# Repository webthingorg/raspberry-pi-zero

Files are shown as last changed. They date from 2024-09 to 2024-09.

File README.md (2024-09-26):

📸 Raspberry Pi Zero Hardware

## Pictures

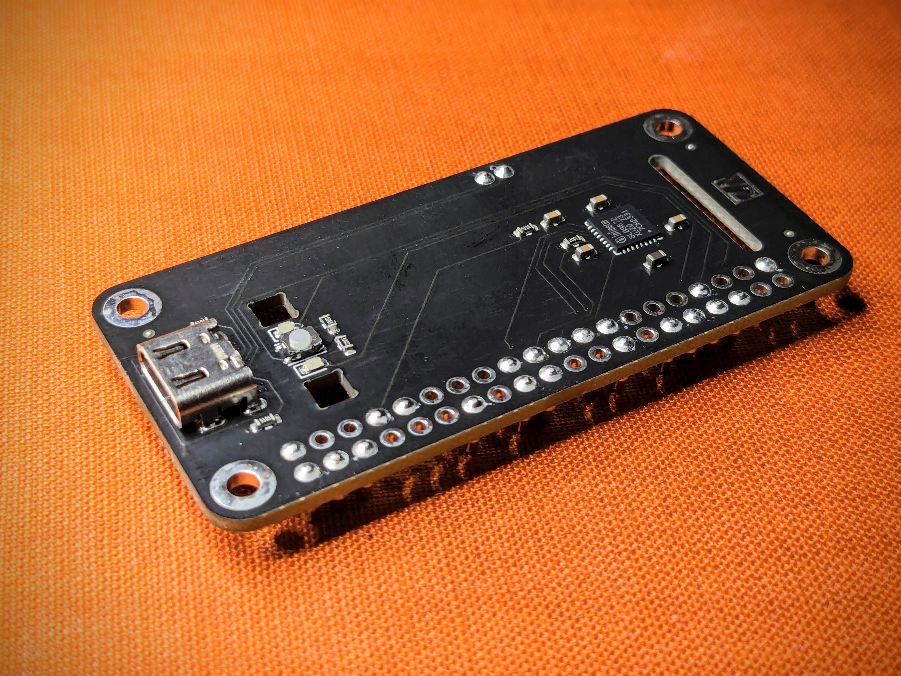
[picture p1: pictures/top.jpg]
top


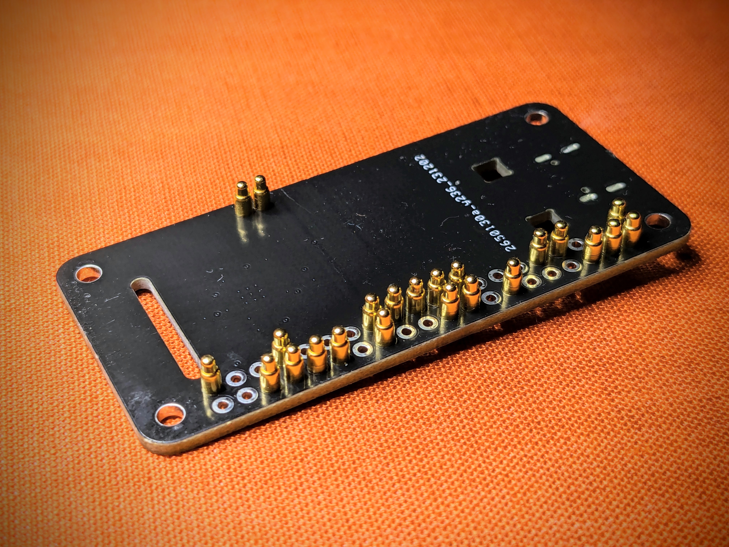
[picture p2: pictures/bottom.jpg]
bottom


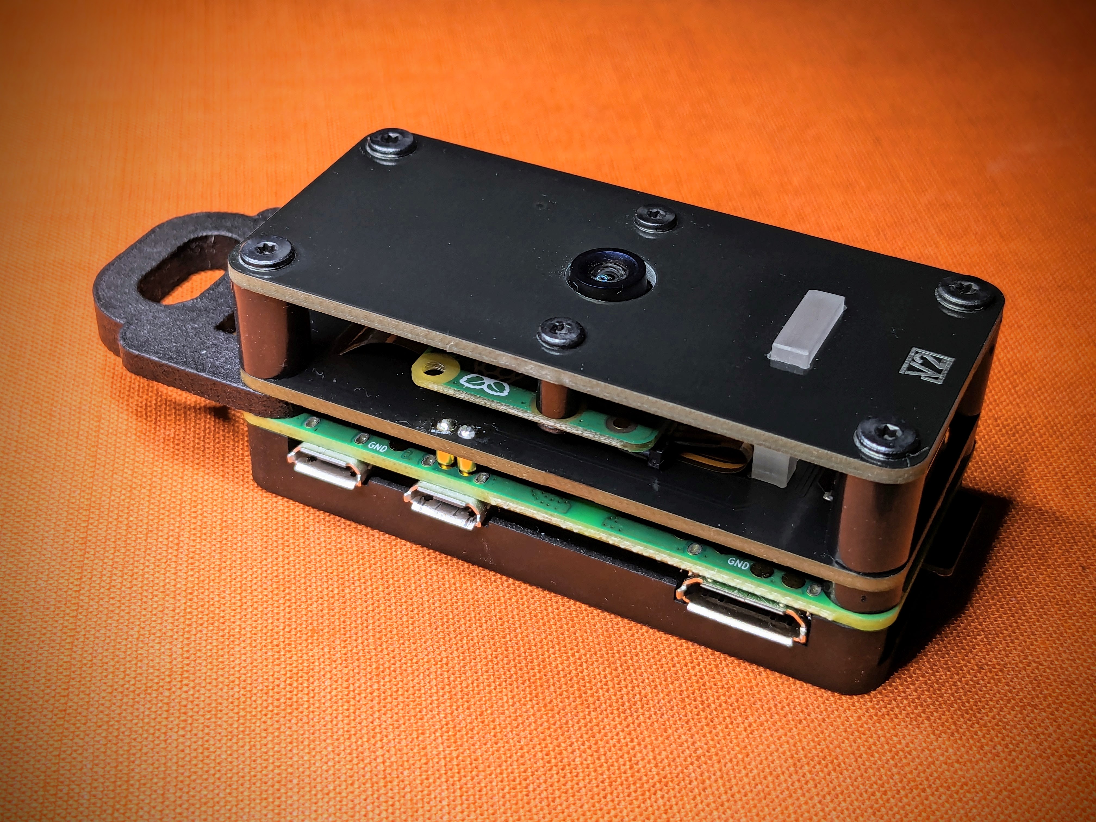
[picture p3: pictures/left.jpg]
left


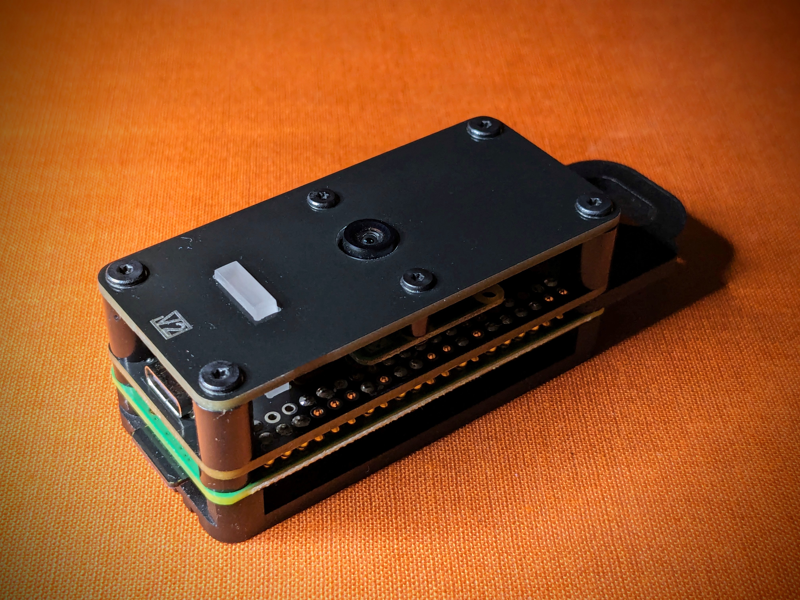
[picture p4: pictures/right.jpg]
rigth


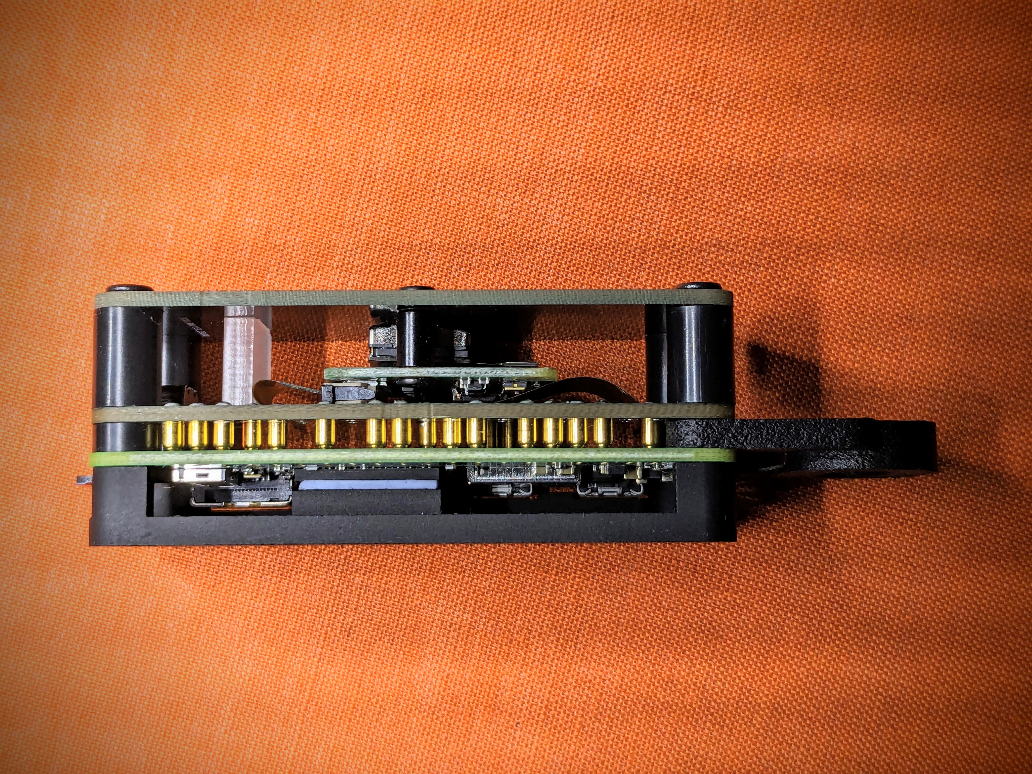
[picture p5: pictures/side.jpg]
side


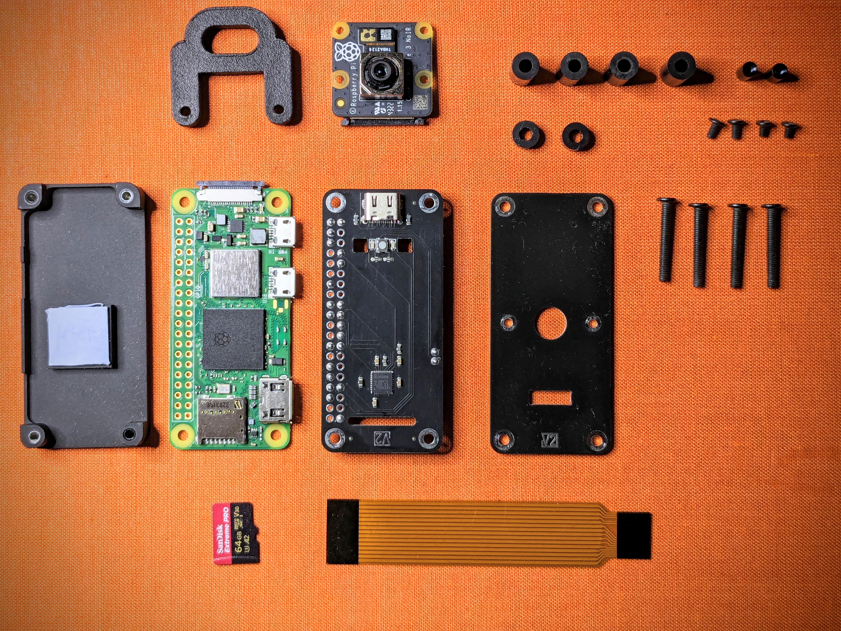
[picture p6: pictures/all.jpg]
all


## Schematic

[PDF](raspberry-pi-zero.pdf)

## Bill Of Materials

[Interactive BOM](https://gitlab.com/webthing.org/raspberry-pi-zero/-/raw/main/raspberry-pi-zero-bom.html?inline=false)

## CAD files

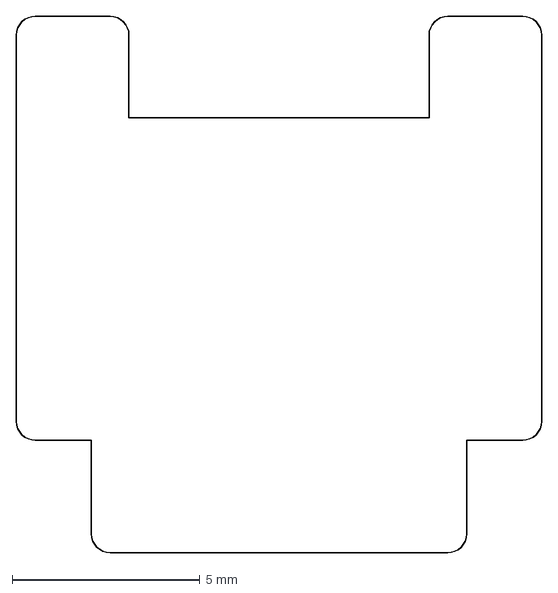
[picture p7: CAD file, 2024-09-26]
button-laser-10mm.dxf
14.0 x 14.3 mm

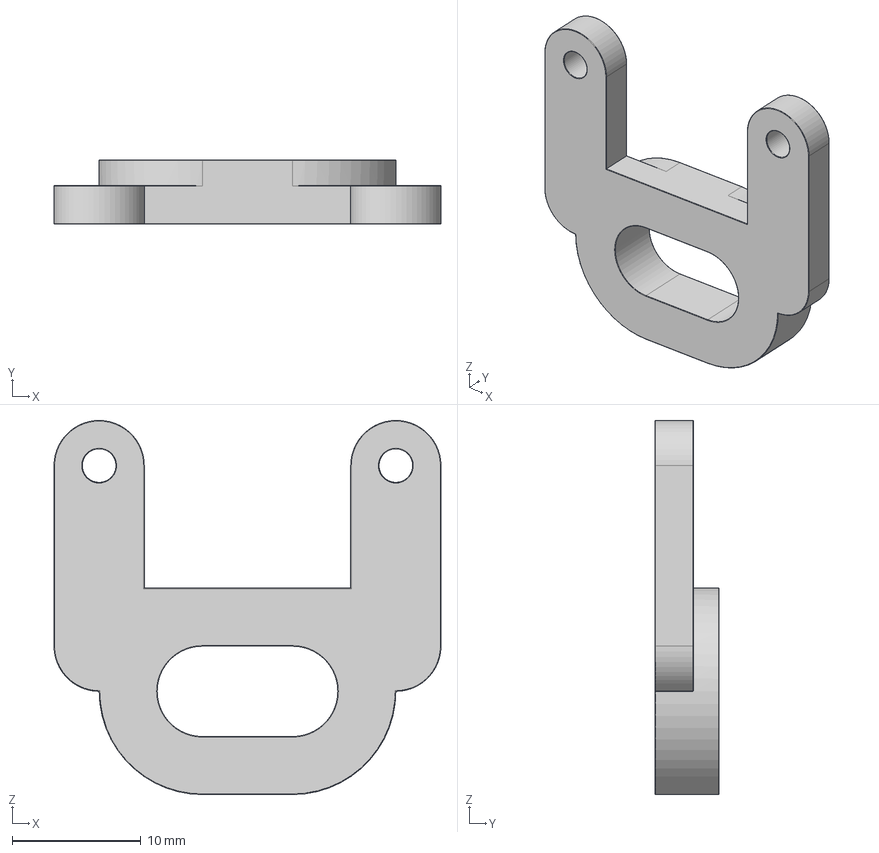
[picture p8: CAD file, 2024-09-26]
hanger.step
30.0 x 5.00 x 29.0 mm

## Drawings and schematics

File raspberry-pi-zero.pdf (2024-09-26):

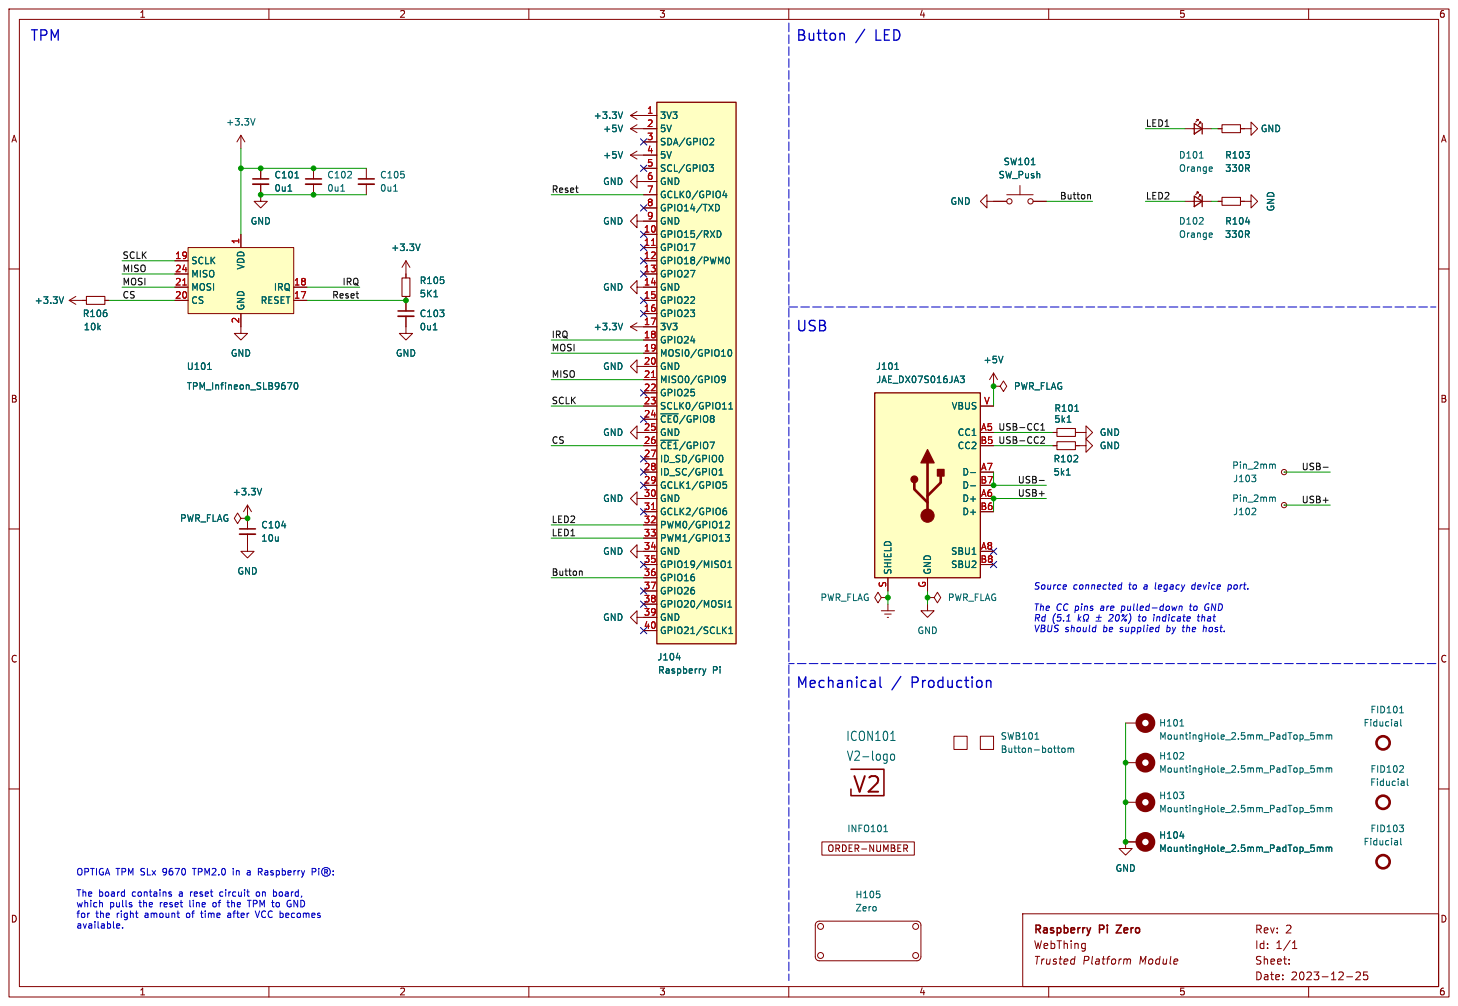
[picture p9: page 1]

SW101 SW_Push GND GND GND GND

for the right amount of time after VCC becomes available.

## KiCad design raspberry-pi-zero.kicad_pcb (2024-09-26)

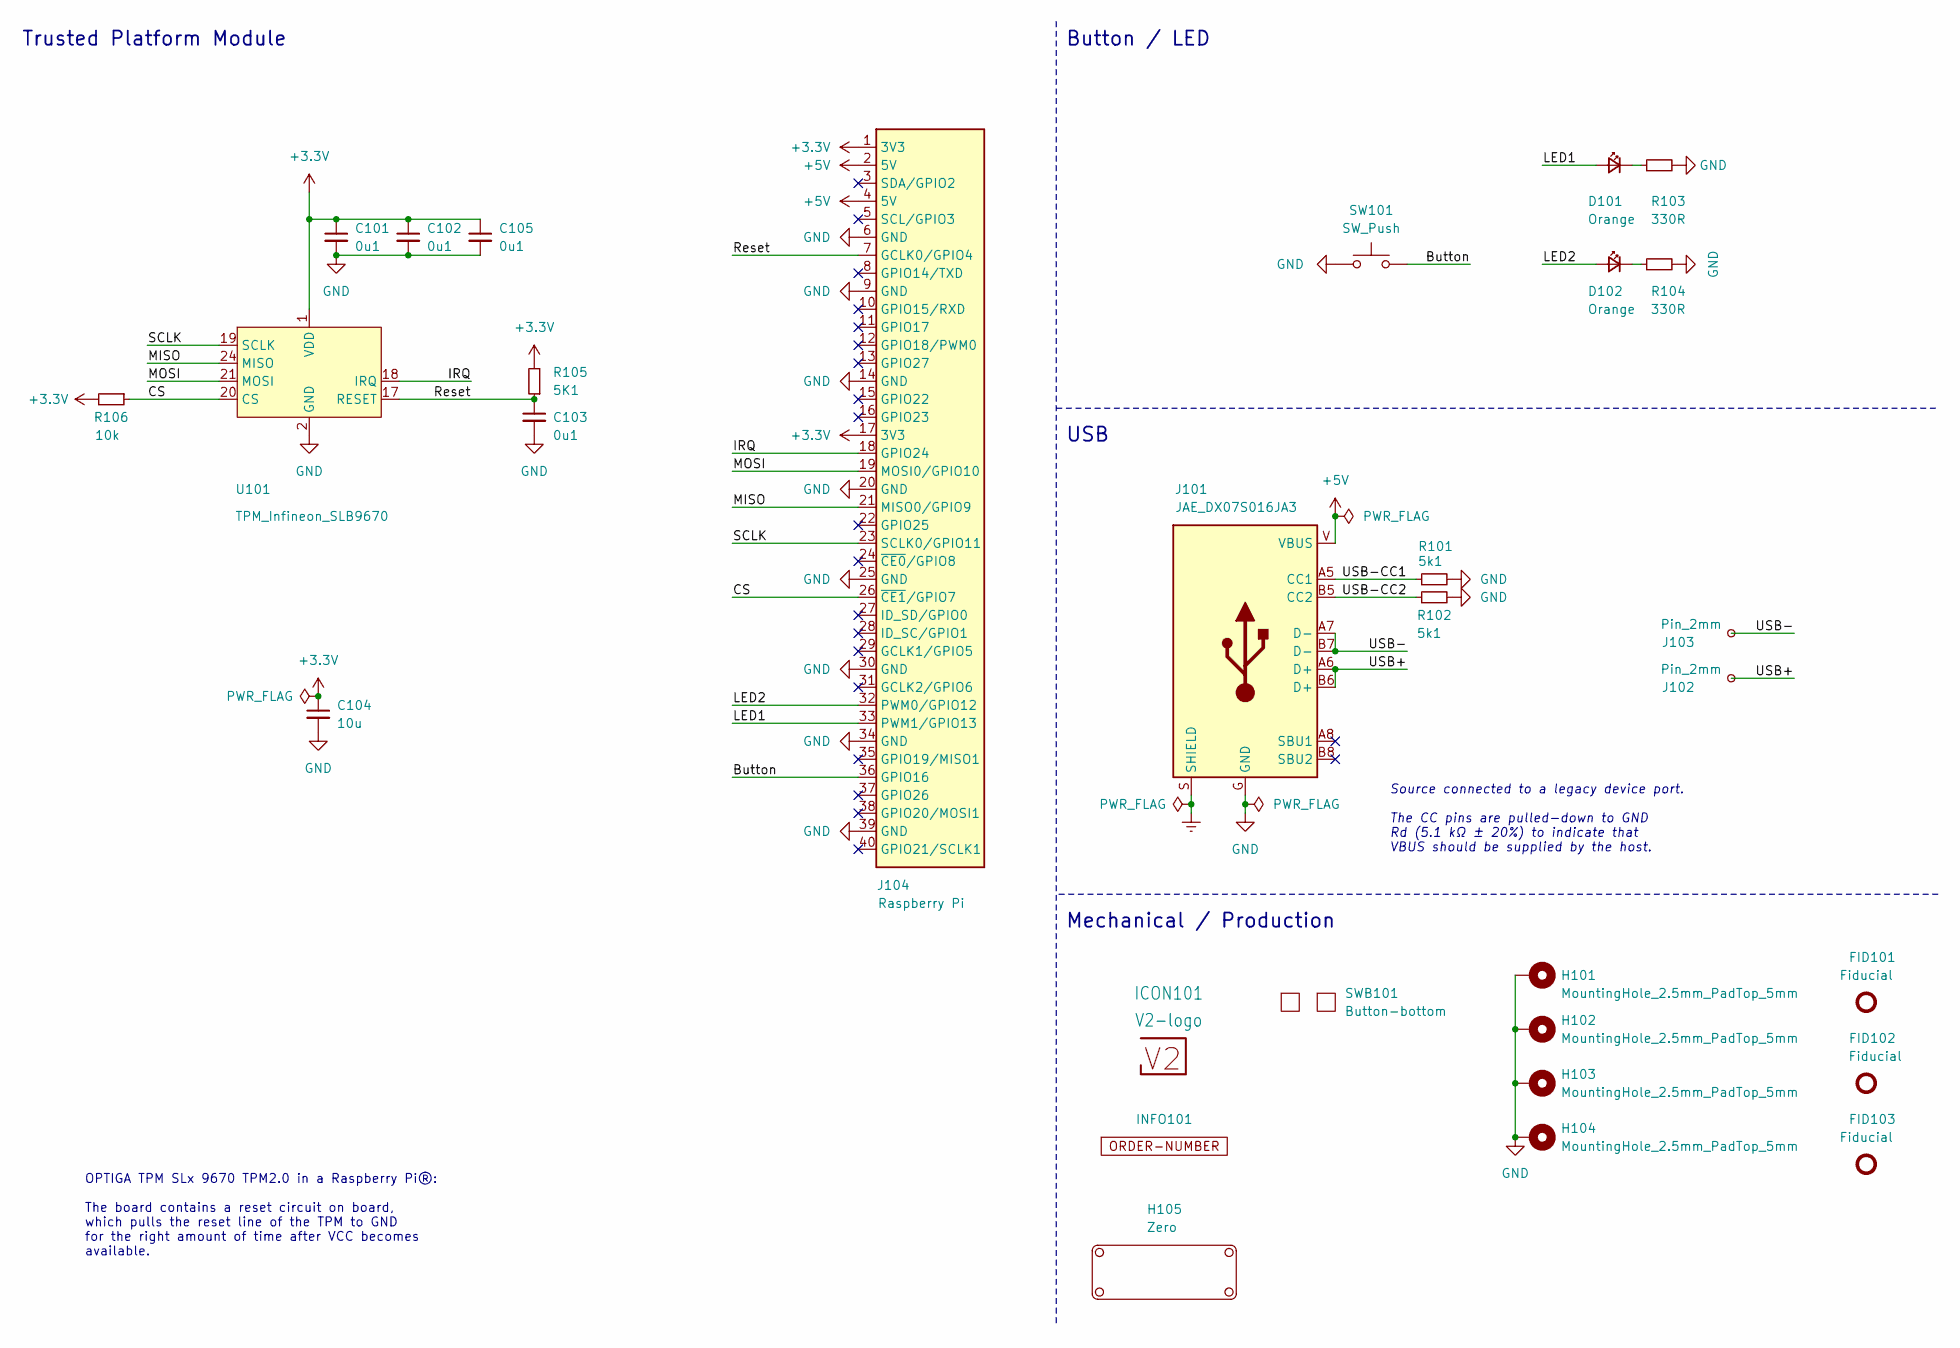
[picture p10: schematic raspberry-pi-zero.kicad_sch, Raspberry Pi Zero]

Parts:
C101, C102, C103, C105: 0u1; C_0603_1608Metric
C104: 10u; C_0603_1608Metric
D101, D102: Orange; LED_0603_1608Metric
FID101, FID102, FID103: Fiducial; Fiducial_0.5mm_Mask1mm_Paste
H101, H102, H103, H104: MountingHole_2.5mm_PadTop_5mm
H105: Zero
ICON101: V2-logo; Logo_Small
INFO101: ORDER-NUMBER; Order_Number
J101: JAE_DX07S016JA3
J102, J103: Pin_2mm
J104: Raspberry Pi; Connector_PogoPins
R101, R102: 5k1; R_0603_1608Metric
R103, R104: 330R; R_0603_1608Metric
R105: 5K1; R_0603_1608Metric
R106: 10k; R_0603_1608Metric
SW101: SW_Push; SKSG
SWB101: Button-bottom; PCB_Button-bottom
U101: TPM_Infineon_SLB9670; QFN-32-1EP_5x5mm_P0.5mm_EP3.6x3.6mm_ThermalVias

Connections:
+3.3V: C101.1, C102.1, C104.1, C105.1, J104.1 (3V3), J104.17 (3V3), R105.2, R106.2, U101.1 (VDD), U101.8 (VDD), U101.14 (VDD), U101.22 (VDD)
+5V: J101.V (VBUS), J104.2 (5V), J104.4 (5V)
/Button: J104.36 (GPIO16), SW101.2
/CS: J104.26 (~CE1/GPIO7), R106.1, U101.20 (CS)
/IRQ: J104.18 (GPIO24), U101.18 (IRQ)
/LED1: D101.2 (A), J104.33 (PWM1/GPIO13)
/LED2: D102.2 (A), J104.32 (PWM0/GPIO12)
/MISO: J104.21 (MISO0/GPIO9), U101.24 (MISO)
/MOSI: J104.19 (MOSI0/GPIO10), U101.21 (MOSI)
/Reset: C103.1, J104.7 (GCLK0/GPIO4), R105.1, U101.17 (RESET)
/SCLK: J104.23 (SCLK0/GPIO11), U101.19 (SCLK)
/USB+: J101.A6 (D+), J101.B6 (D+), J102.1
/USB-: J101.A7 (D-), J101.B7 (D-), J103.1
/USB-CC1: J101.A5 (CC1), R101.1
/USB-CC2: J101.B5 (CC2), R102.1
Earth: J101.S (SHIELD)
GND: C101.2, C102.2, C103.2, C104.2, C105.2, H101.1, H102.1, H103.1, H104.1, J101.G (GND), J104.6 (GND), J104.9 (GND), J104.14 (GND), J104.20 (GND), J104.25 (GND), J104.30 (GND), J104.34 (GND), J104.39 (GND), R101.2, R102.2, R103.2, R104.2, SW101.1, U101.2 (GND), U101.9 (GND), U101.16 (GND), U101.23 (GND), U101.32 (GND), U101.33 (GND)
unnamed: D101.1 (K), R103.1
unnamed: D102.1 (K), R104.1

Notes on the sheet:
Button / LED
Trusted Platform Module
 Source connected to a legacy device port. The CC pins are pulled-down to GND Rd (5.1 kΩ ± 20%) to indicate that VBUS should be supplied by the host.
Mechanical / Production
OPTIGA TPM SLx 9670 TPM2.0 in a Raspberry Pi®: The board contains a reset circuit on board, which pulls the reset line of the TPM to GND for the right amount of time after VCC becomes available.
USB

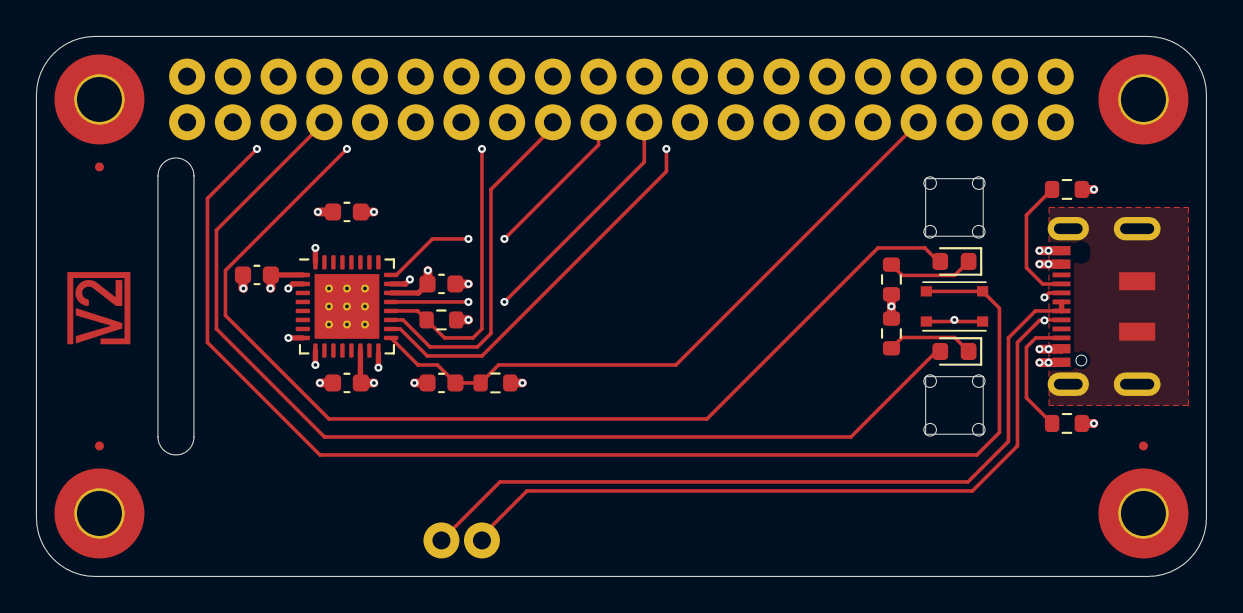
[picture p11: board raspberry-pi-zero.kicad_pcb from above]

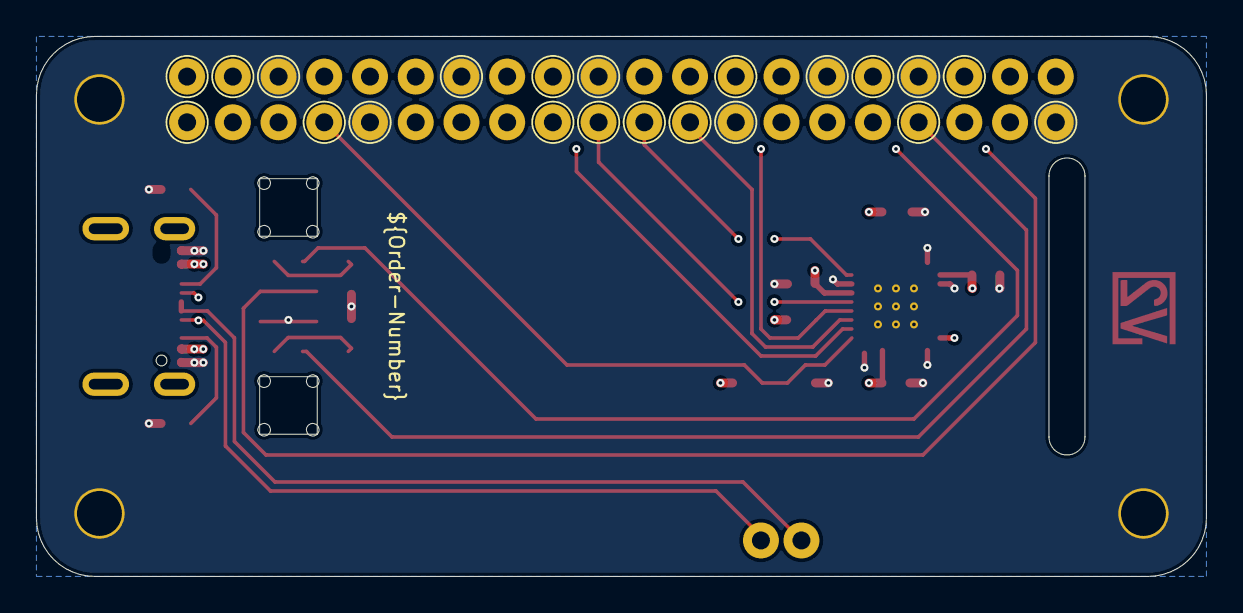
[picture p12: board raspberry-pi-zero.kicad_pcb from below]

Board: 4 copper layers, 65.0 x 30.0 mm, 30 parts (2 on the bottom side), 18 nets.
